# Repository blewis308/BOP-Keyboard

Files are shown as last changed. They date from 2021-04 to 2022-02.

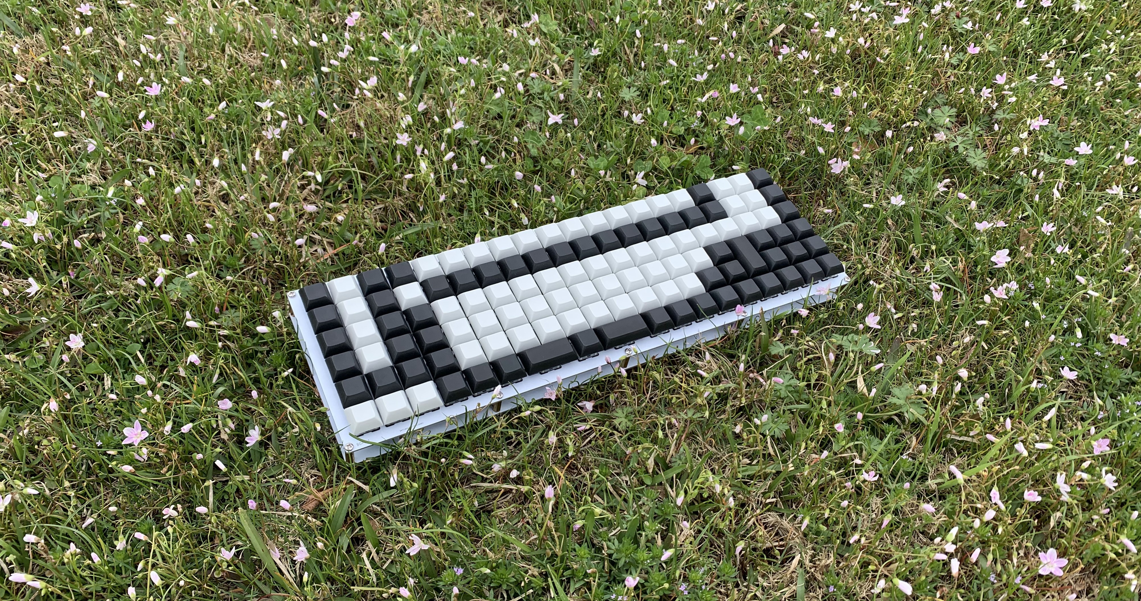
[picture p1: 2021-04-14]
Pictures/IMG_6860_cropped.jpg

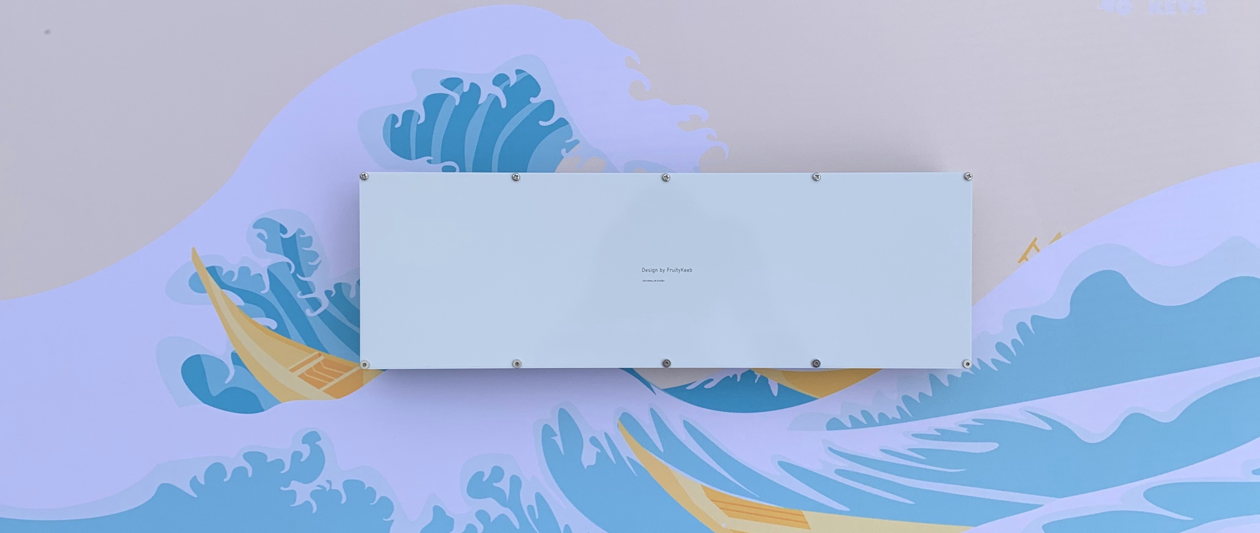
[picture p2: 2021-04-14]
Pictures/IMG_6852_cropped.jpg

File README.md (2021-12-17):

# BOP-Keyboard

BOP stands for Big Ortho Project, a 6 row by 20 column ortholinear keyboard running off of the Teensy++2.0 Controller.

## Jump to...
* [What's included](#included-in-the-box)
* [Build Guide](#build-guide)
  
## REPO Contents:
* Plate File in `.dxf` format, perfect for creating a 3D printed case from.
* Various Pictures of the Prototype boards, also shown below.
* QMK Hex and firmware coming soontm

**Open Sourced PCB Files are for PERSONAL use only. Use for Commercial purposes without written permission is strictly prohibited.**

### Pictures

Image of BOP
Image of BOP
Image of BOP

# Included in the Box:
#### Diodes - About 130x (120 needed)
Image of Diodes
#### Standoffs + Screws - M3 Size (10x Standoffs and 20x Screws)
Image of Standoffs
#### Controller Headers - 2x 20 pin male and female headers
Image of Headers
#### Stabilizers - 3x 2u Stabilizers
Image of Stabilizers
#### Rubber Feet - 8x Feet
Image of Feet
#### Controller - 1x Teensy++2.0 Micro Controller
Image of controller

# Build Guide:
## Total Estimated Time: 4-5 hours

## Before you begin! 
#### Please test your board, some boards have shown signs of multiple switches actuating at the same time or switches that are shorting out with nearby ones. You can test this by using a multimeter in continuity mode and test each pin on the socket to pins in the rows. If anything is wrong, please contact me via Discord DM or email and I'll work with you to take care of the issue.

### Step 1: Diodes
#### Estimated Time: 2-3 hours
[This is a really good video on how to solder smd diodes](https://youtu.be/Jpj3tilIaik?t=187). I recommend you watch this before soldering.

Start by orienting the PCB so that you can read "Design by Fruitykeeb" straight on. Next, place a small amound of solder the pad opposite to the "K" on each of the diode locations.

Image of half pad

Next, using tweezers or something similar, grab one diode and heat the bit of solder you just placed. Once the solder starts to melt, slide the diode into position. **Make sure the line on the diode is facing the "K" on the footprint. If it is not, key presses will not register!**

Image of diode on

Finish the diodes by adding solder to the other pad. 

### Step 2: Headers
#### Estimated Time: 5-15 minutes

Keeping on the same side as the diodes, set the female headers onto the pcb. Making sure they are straight vertically, use tape to hold them in place. 

Image of headers

Flip the pcb over and solder the headers in place. **Make sure there are no shorts between pins.**

Next, place the male headers onto the controller. The USB port should be facing up, leave the longer legs up as well. Using tape to hold them im place, flip the controller over and solder them in. Again, make sure there are no shorts between pins. 

Press the controller in to test fit, but remove for flashing and switches.

Image of controller

### Step 3: Flashing the controller
#### Estimated Time: 5 minutes

My using [QMK Toolbox](https://github.com/qmk/qmk_toolbox), Open the default hex in the /keymaps/hex folder of this repo. 

In the MCU dropdown, select the `at90usb1286` option. Plug in the Teensy++2.0 and press the reset button at the bottom, then click `Flash` in the toolbox, this will flash the controller to the keymap you specify.

Press the controller in and using Via and tweezers, bridge the contacts where the switches would be to test each key. 

> If there is an issue where the last column spams the keys, there is a workaround detailed [here](#the-workaround).

### Step 4: Switches
#### Estimated Time: 45 mins - 1 hour.

**If you are using stabilizers, put your stabilizers in now.**

Start by pressing some switches into the plate. I recommend switches placed as in the picture below, but use enough so the plate doesn't fall down.
Image of plate with switches

Flip the board over and solder in these first. **Note:** If you have a white pcb, the tolerances are tighter which makes pressing in switches harder. Double check that each switch is pressed fully in before soldering.

After these first switches are in, press in the remaining switches. Keep in mind that the top row, second column switch is rotated 180 from all the other switches.

Then, solder in the rest of the switches. Finally, press in the controller.

Image of all switches in

### Step 5: Standoffs and Bottom Plate
#### Estimated Time: 5 minutes

Start by placing a screw in the switch plate, then thread the standoff onto it. Repeat this for all 10 holes. Flip the whole board over and set the bottom plate on top; you shoudl be able to read "BOP".

Using a screw driver, screw in the remaining screws and then place the rubber feet around the edge of the board.

### Step 6: Enjoy!

Congratulations! You finished your BOP build! Add switches and start typing away!

## The Workaround:
If you have an issue with your board spamming the far right column of keys, use this workaround. 

On the bottom side of the controller, solder a short between pins C6 and C7. In the `config.h` file, change the last item in the `MATRIX_COL_PINS` array from C7 to C6.

Recompile the hex and reflash the MCU. This should fix the problem.

If this still does not work, clip the pins that go to ground from the micro controller.

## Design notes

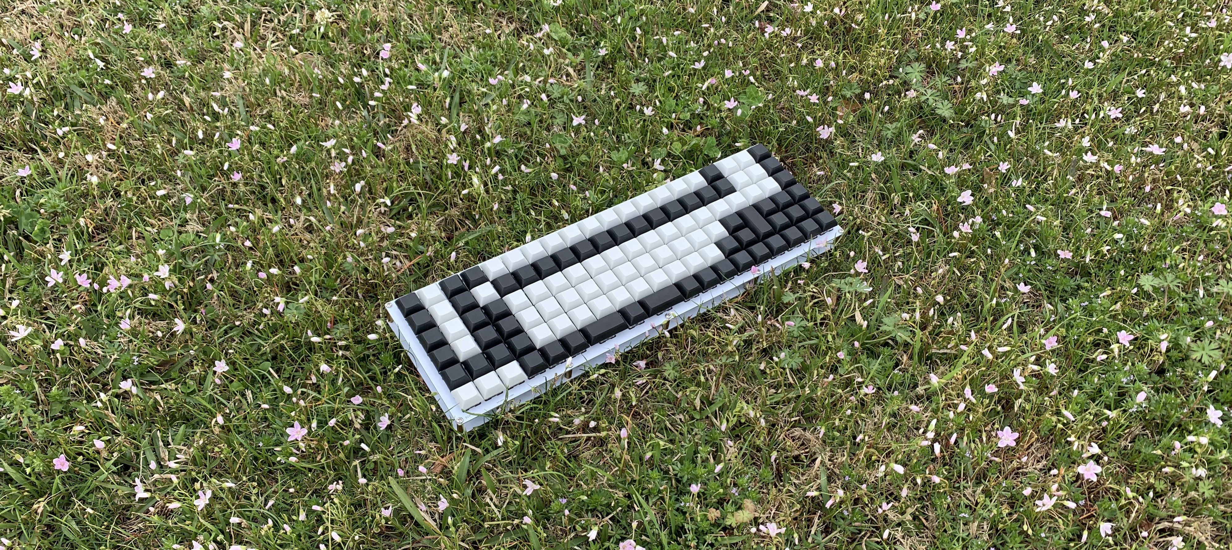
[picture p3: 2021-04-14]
Pictures/IMG_6861_cropped.jpg

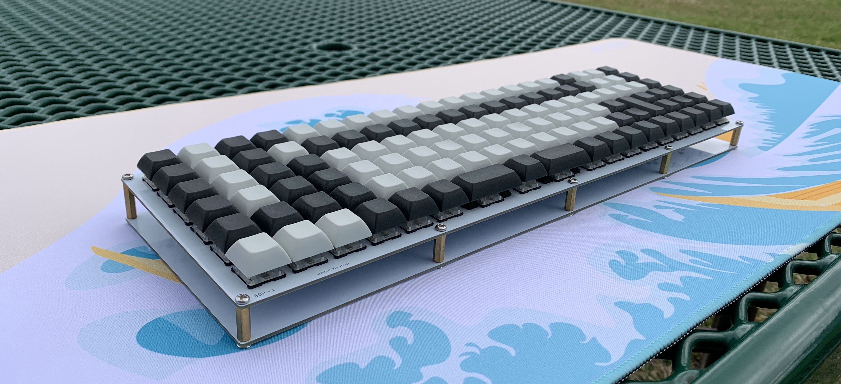
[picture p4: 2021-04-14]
Pictures/IMG_6857_cropped.jpg

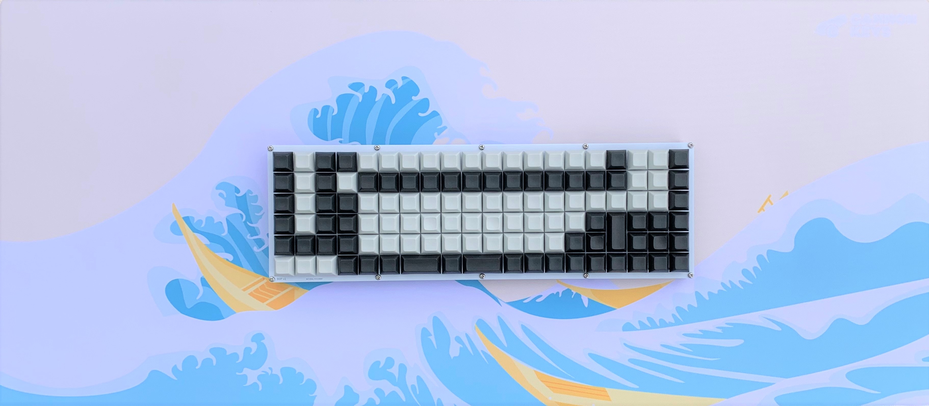
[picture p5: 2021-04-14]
Pictures/IMG_6850_cropped_filter.jpg

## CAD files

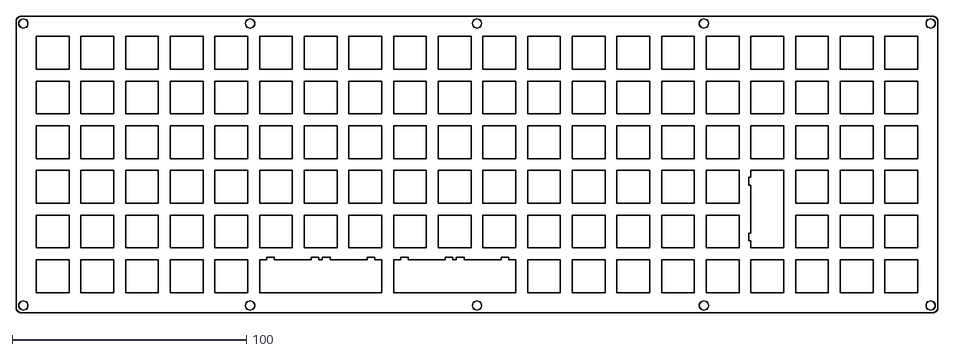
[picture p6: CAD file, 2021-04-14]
Plate/plate v1.1.dxf
393.0 x 126.3

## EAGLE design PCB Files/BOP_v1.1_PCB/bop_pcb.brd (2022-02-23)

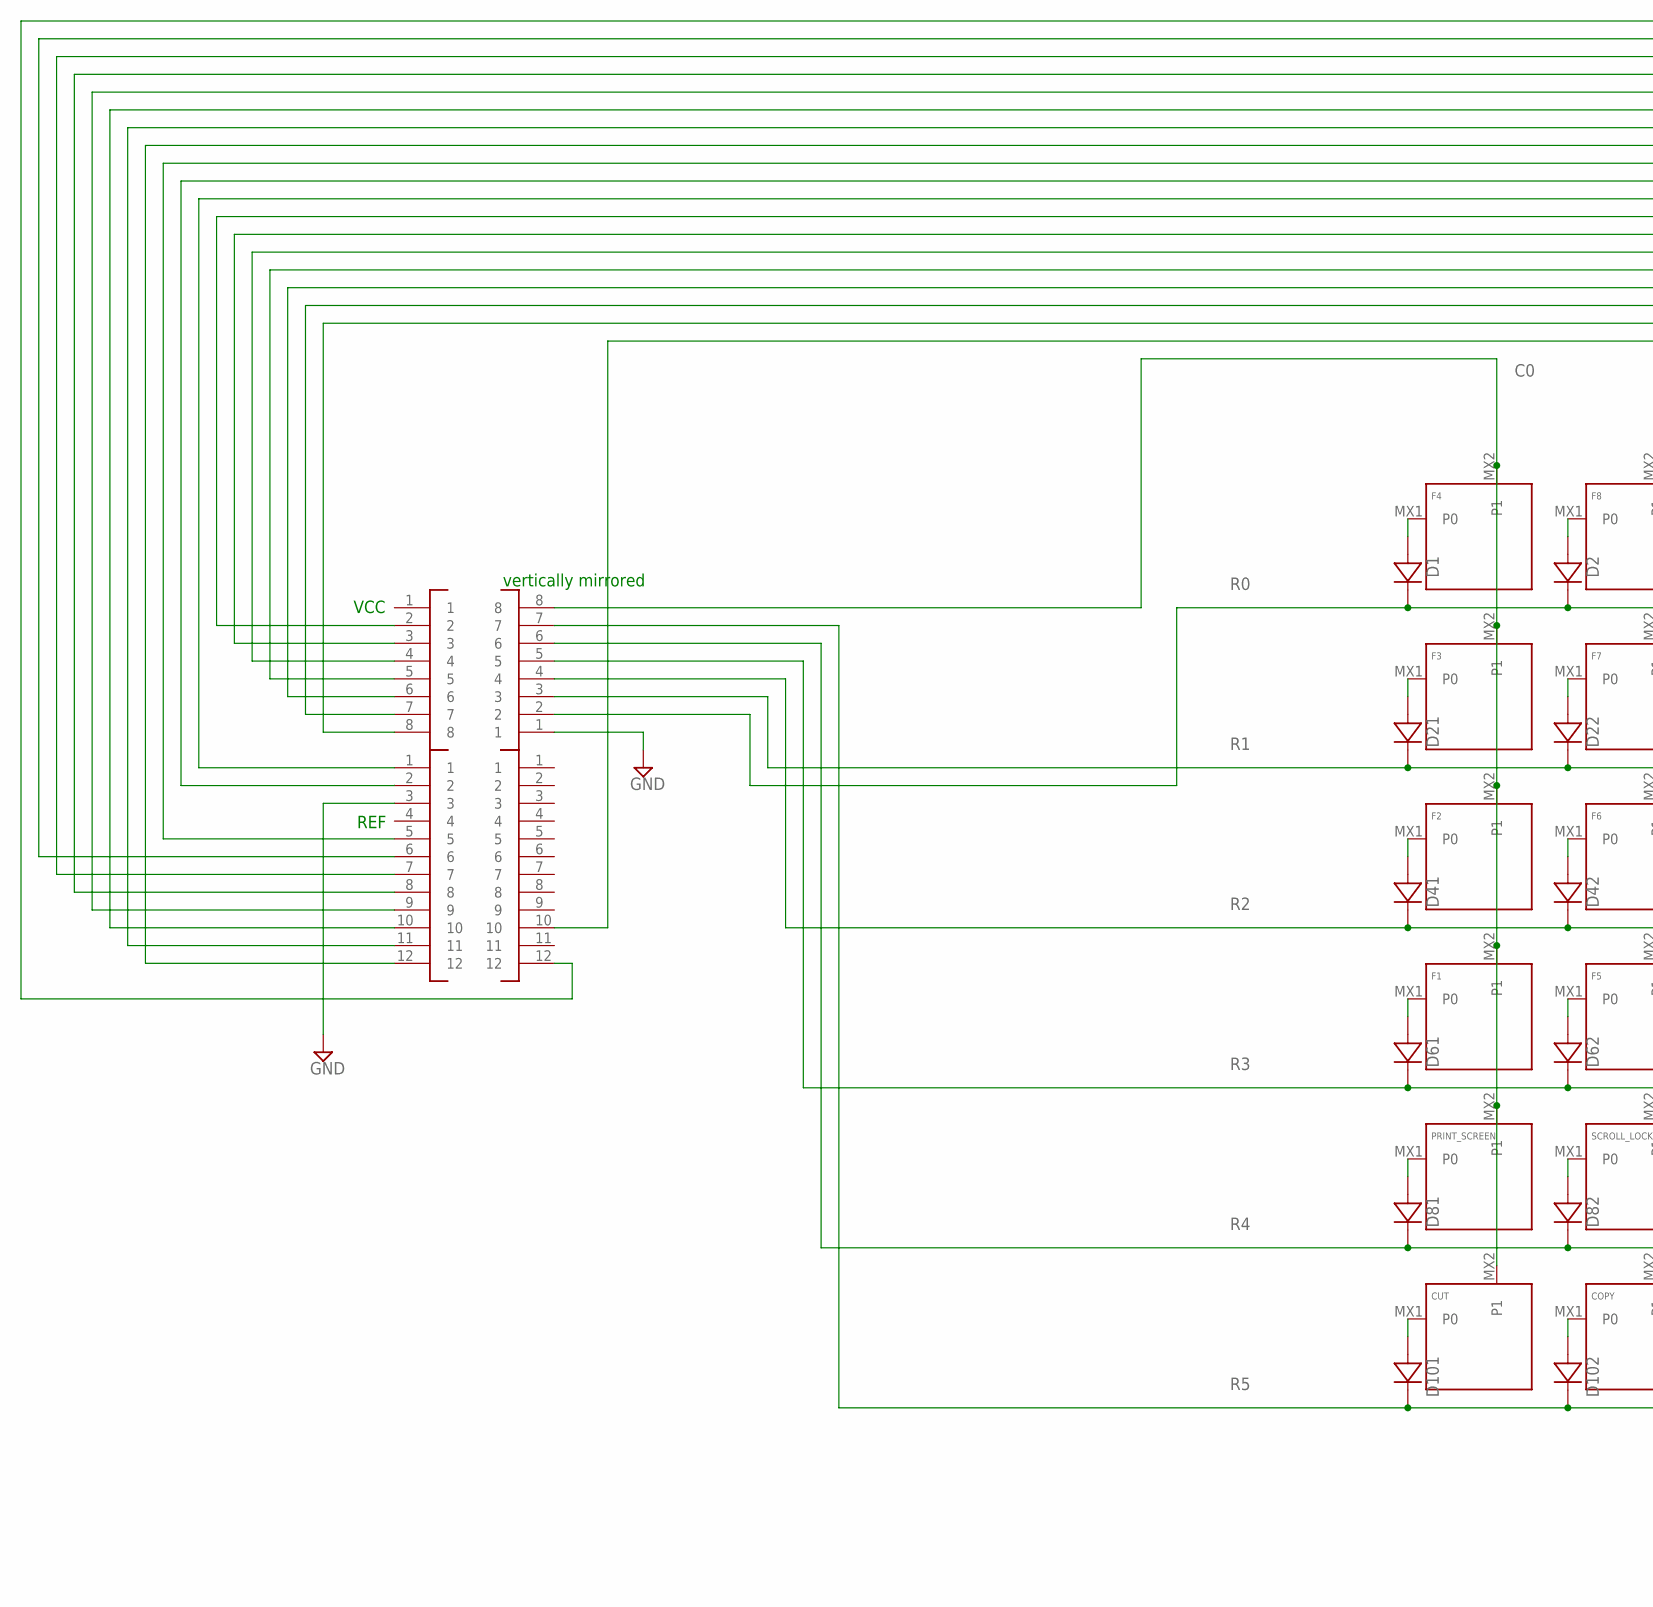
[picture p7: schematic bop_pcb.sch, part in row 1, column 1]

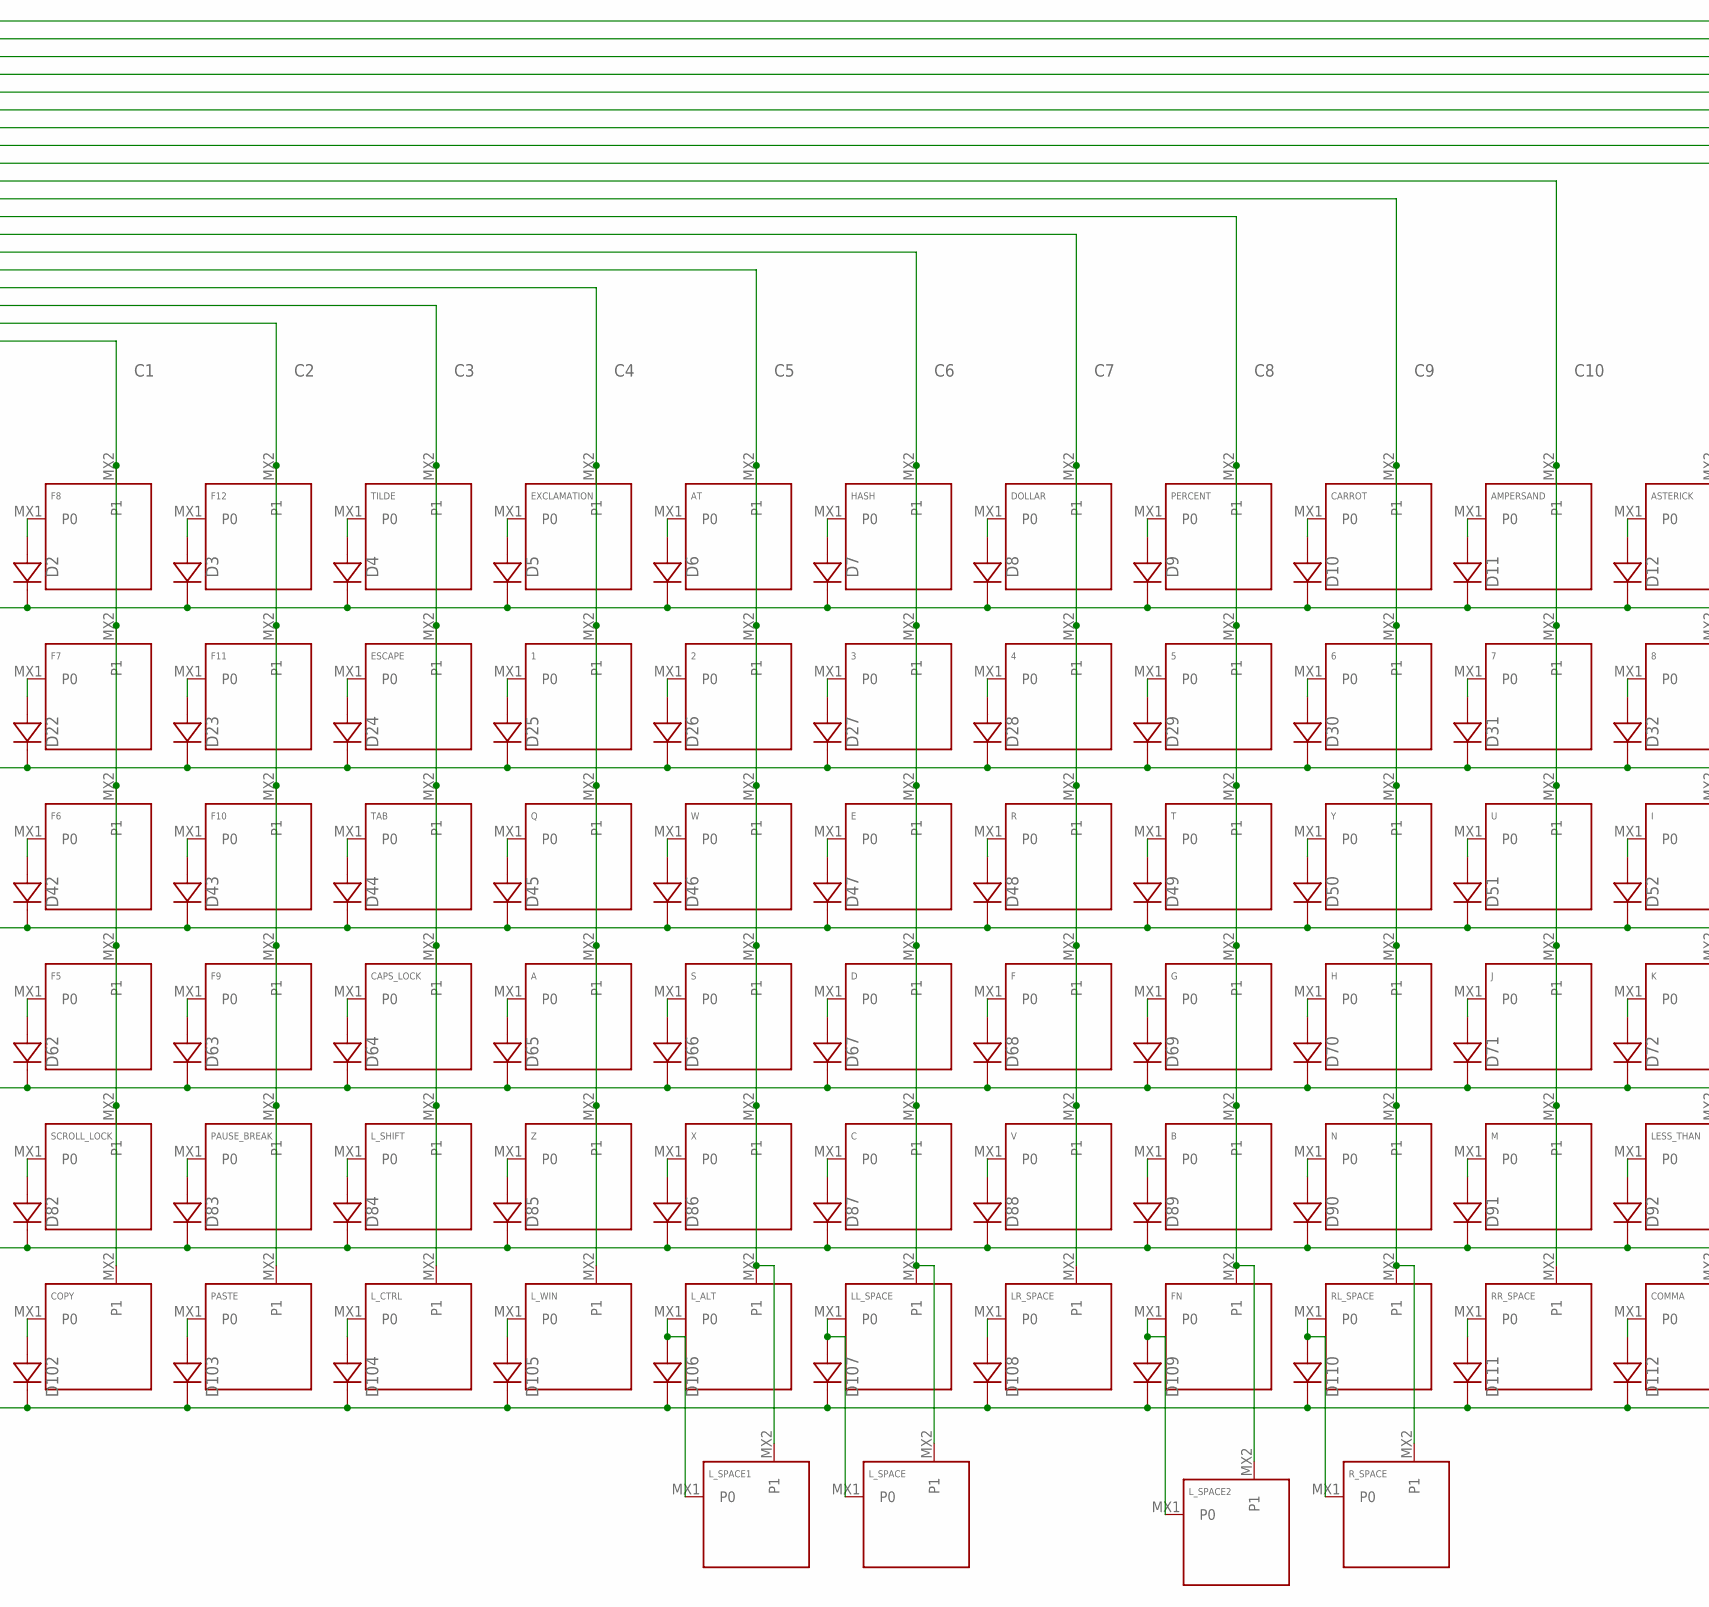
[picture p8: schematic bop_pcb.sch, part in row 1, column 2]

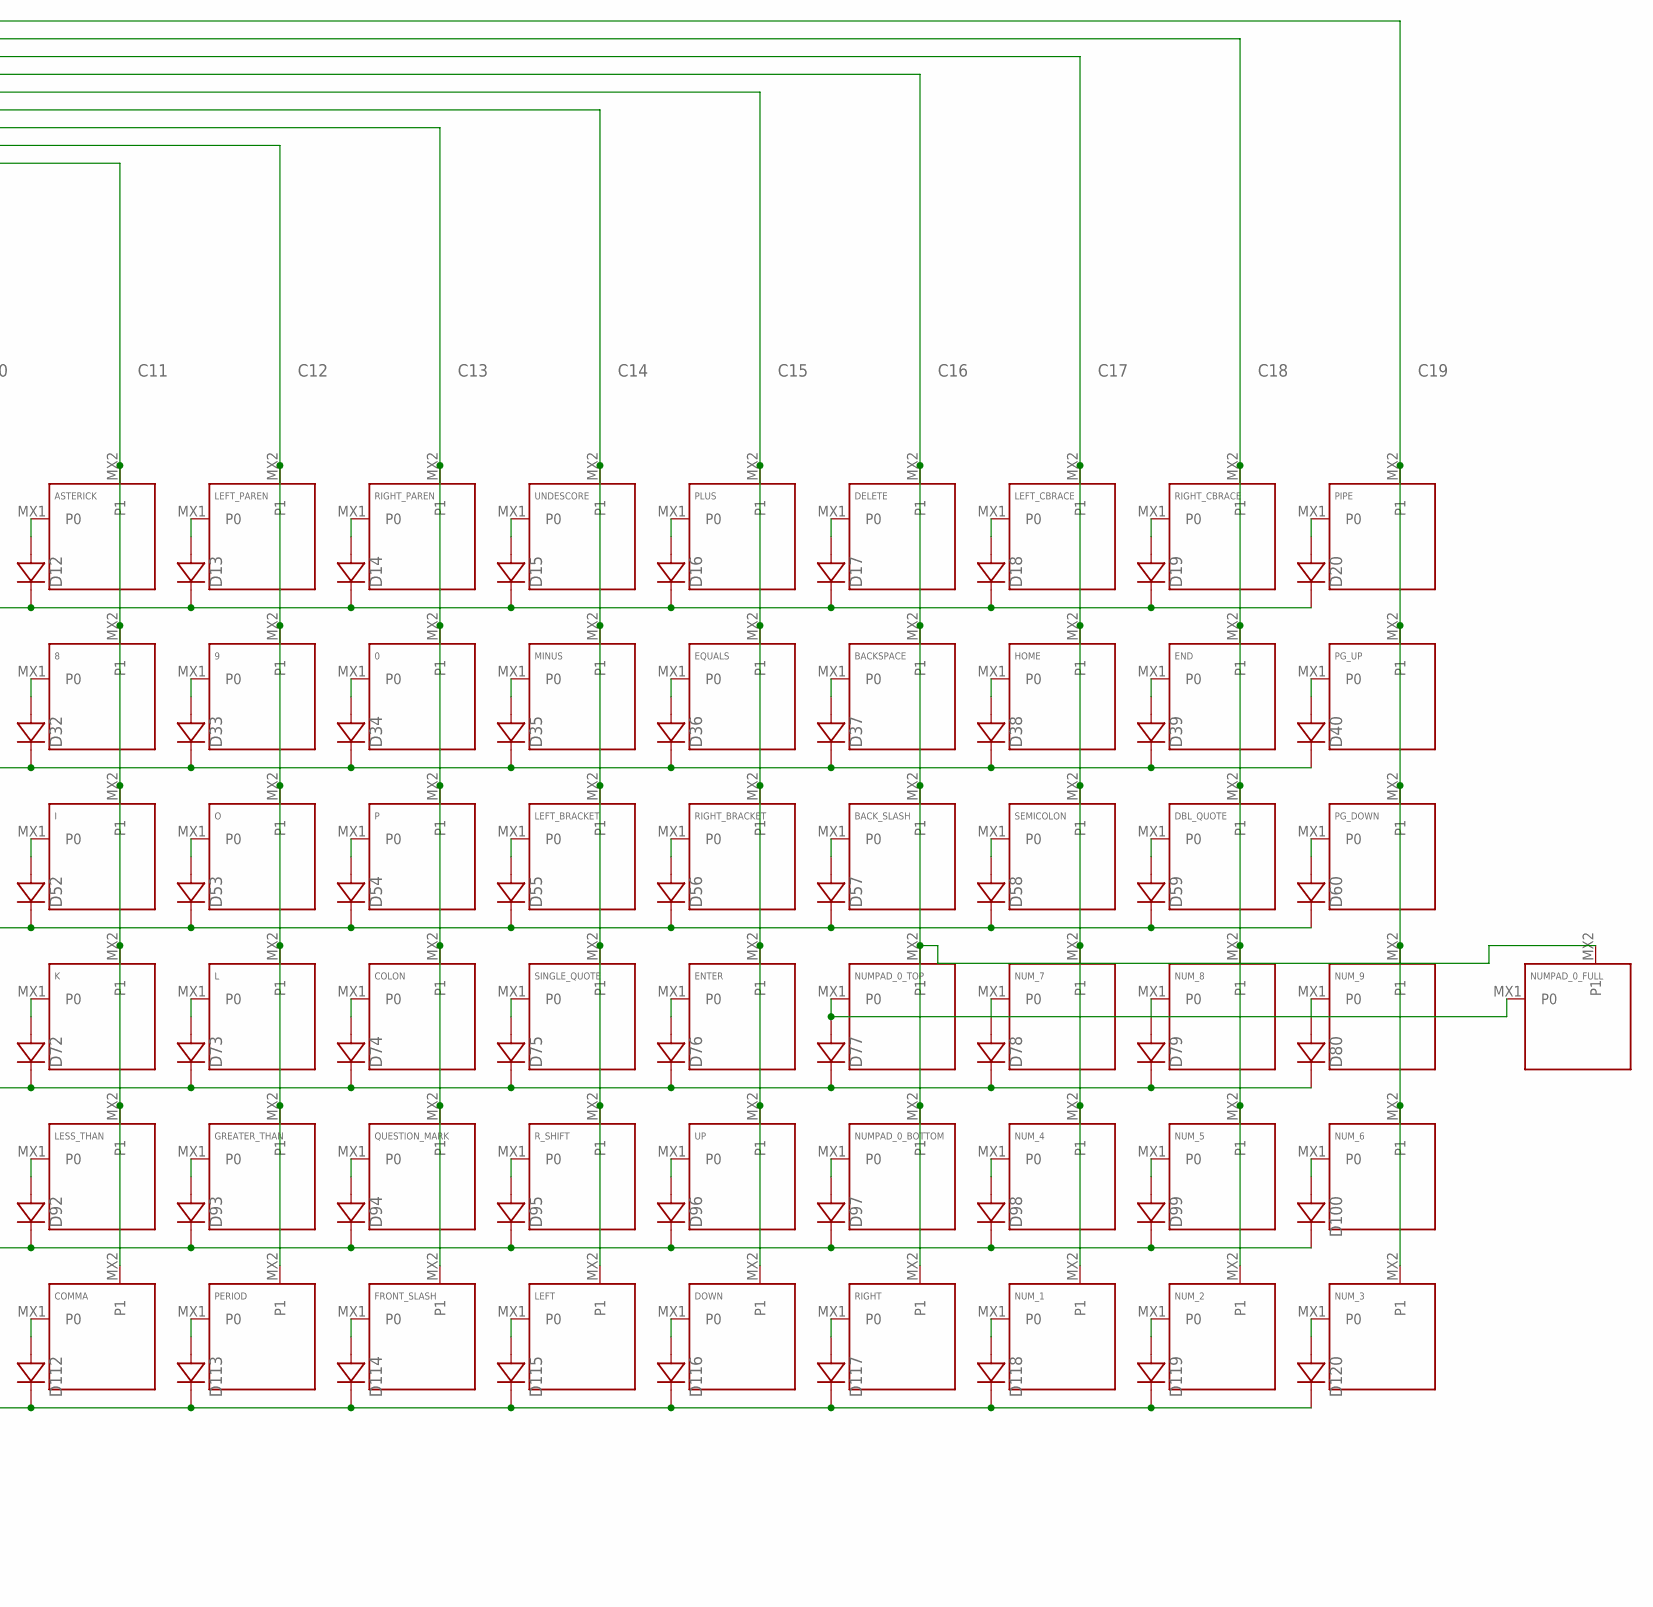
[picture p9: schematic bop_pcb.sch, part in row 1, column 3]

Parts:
0, 1, 2, 3, 4, 5, 6, 7, 8, 9: KEYSWITCH-PLAIN-MX-1U; MX-1U
A: KEYSWITCH-PLAIN-MX-1U; MX-1U
AMPERSAND: KEYSWITCH-PLAIN-MX-1U; MX-1U
ASTERICK: KEYSWITCH-PLAIN-MX-1U; MX-1U
AT: KEYSWITCH-PLAIN-MX-1U; MX-1U
B: KEYSWITCH-PLAIN-MX-1U; MX-1U
BACKSPACE: KEYSWITCH-PLAIN-MX-1U; MX-1U
BACK_SLASH: KEYSWITCH-PLAIN-MX-1U; MX-1U
C: KEYSWITCH-PLAIN-MX-1U; MX-1U
CAPS_LOCK: KEYSWITCH-PLAIN-MX-1U; MX-1U
CARROT: KEYSWITCH-PLAIN-MX-1U; MX-1U
COLON: KEYSWITCH-PLAIN-MX-1U; MX-1U
COMMA: KEYSWITCH-PLAIN-MX-1U; MX-1U
COPY: KEYSWITCH-PLAIN-MX-1U; MX-1U
CUT: KEYSWITCH-PLAIN-MX-1U; MX-1U
D: KEYSWITCH-PLAIN-MX-1U; MX-1U
D1, D2, D3, D4, D5, D6, D7, D8, D9, D10, D11, D12, D13, D14, D15, D16, D17, D18, D19, D20, D21, D22, D23, D24, D25, D26, D27, D28, D29, D30, D31, D32, D33, D34, D35, D36, D37, D38, D39, D40, D41, D42, D43, D44, D45, D46, D47, D48, D49, D50, D51, D52, D53, D54, D55, D56, D57, D58, D59, D60, D61, D62, D63, D64, D65, D66, D67, D68, D69, D70, D71, D72, D73, D74, D75, D76, D77, D78, D79, D80, D81, D82, D83, D84, D85, D86, D87, D88, D89, D90, D91, D92, D93, D94, D95, D96, D97, D98, D99, D100, D101, D102, D103, D104, D105, D106, D107, D108, D109, D110, D111, D112, D113, D114, D115, D116, D117, D118, D119, D120: DIODE-SOD-123; SOD-123
DBL_QUOTE: KEYSWITCH-PLAIN-MX-1U; MX-1U
DELETE: KEYSWITCH-PLAIN-MX-1U; MX-1U
DOLLAR: KEYSWITCH-PLAIN-MX-1U; MX-1U
DOWN: KEYSWITCH-PLAIN-MX-1U; MX-1U
E: KEYSWITCH-PLAIN-MX-1U; MX-1U
END: KEYSWITCH-PLAIN-MX-1U; MX-1U
ENTER: KEYSWITCH-PLAIN-MX-1U; MX-1U
EQUALS: KEYSWITCH-PLAIN-MX-1U; MX-1U
ESCAPE: KEYSWITCH-PLAIN-MX-1U; MX-1U
EXCLAMATION: KEYSWITCH-PLAIN-MX-1U; MX-1U
F, F1, F2, F3, F4, F5, F6, F7, F8, F9, F10, F11, F12: KEYSWITCH-PLAIN-MX-1U; MX-1U
FN: KEYSWITCH-PLAIN-MX-1U; MX-1U
FRONT_SLASH: KEYSWITCH-PLAIN-MX-1U; MX-1U
G: KEYSWITCH-PLAIN-MX-1U; MX-1U
GREATER_THAN: KEYSWITCH-PLAIN-MX-1U; MX-1U
H: KEYSWITCH-PLAIN-MX-1U; MX-1U
HASH: KEYSWITCH-PLAIN-MX-1U; MX-1U
HOME: KEYSWITCH-PLAIN-MX-1U; MX-1U
I: KEYSWITCH-PLAIN-MX-1U; MX-1U
J: KEYSWITCH-PLAIN-MX-1U; MX-1U
J1, J2: HEADER-12X1-2.54-ROUND
K: KEYSWITCH-PLAIN-MX-1U; MX-1U
L: KEYSWITCH-PLAIN-MX-1U; MX-1U
LEFT: KEYSWITCH-PLAIN-MX-1U; MX-1U
LEFT_BRACKET: KEYSWITCH-PLAIN-MX-1U; MX-1U
LEFT_CBRACE: KEYSWITCH-PLAIN-MX-1U; MX-1U
LEFT_PAREN: KEYSWITCH-PLAIN-MX-1U; MX-1U
LESS_THAN: KEYSWITCH-PLAIN-MX-1U; MX-1U
LL_SPACE: KEYSWITCH-PLAIN-MX-1U; MX-1U
LR_SPACE: KEYSWITCH-PLAIN-MX-1U; MX-1U
L_ALT: KEYSWITCH-PLAIN-MX-1U; MX-1U
L_CTRL: KEYSWITCH-PLAIN-MX-1U; MX-1U
L_SHIFT: KEYSWITCH-PLAIN-MX-1U; MX-1U
L_SPACE, L_SPACE1, L_SPACE2: KEYSWITCH-PLAIN-MX-2U; MX-2U
L_WIN: KEYSWITCH-PLAIN-MX-1U; MX-1U
M: KEYSWITCH-PLAIN-MX-1U; MX-1U
MINUS: KEYSWITCH-PLAIN-MX-1U; MX-1U
N: KEYSWITCH-PLAIN-MX-1U; MX-1U
NUMPAD_0_BOTTOM, NUMPAD_0_TOP: KEYSWITCH-PLAIN-MX-1U; MX-1U
NUMPAD_0_FULL: KEYSWITCH-PLAIN-MX-2U; MX-2U
NUM_1, NUM_2, NUM_3, NUM_4, NUM_5, NUM_6, NUM_7, NUM_8, NUM_9: KEYSWITCH-PLAIN-MX-1U; MX-1U
O: KEYSWITCH-PLAIN-MX-1U; MX-1U
P: KEYSWITCH-PLAIN-MX-1U; MX-1U
PASTE: KEYSWITCH-PLAIN-MX-1U; MX-1U
PAUSE_BREAK: KEYSWITCH-PLAIN-MX-1U; MX-1U
PERCENT: KEYSWITCH-PLAIN-MX-1U; MX-1U
PERIOD: KEYSWITCH-PLAIN-MX-1U; MX-1U
PG_DOWN: KEYSWITCH-PLAIN-MX-1U; MX-1U
PG_UP: KEYSWITCH-PLAIN-MX-1U; MX-1U
PIPE: KEYSWITCH-PLAIN-MX-1U; MX-1U
PLUS: KEYSWITCH-PLAIN-MX-1U; MX-1U
PRINT_SCREEN: KEYSWITCH-PLAIN-MX-1U; MX-1U
Q: KEYSWITCH-PLAIN-MX-1U; MX-1U
QUESTION_MARK: KEYSWITCH-PLAIN-MX-1U; MX-1U
R: KEYSWITCH-PLAIN-MX-1U; MX-1U
RIGHT: KEYSWITCH-PLAIN-MX-1U; MX-1U
RIGHT_BRACKET: KEYSWITCH-PLAIN-MX-1U; MX-1U
RIGHT_CBRACE: KEYSWITCH-PLAIN-MX-1U; MX-1U
RIGHT_PAREN: KEYSWITCH-PLAIN-MX-1U; MX-1U
RL_SPACE: KEYSWITCH-PLAIN-MX-1U; MX-1U
RR_SPACE: KEYSWITCH-PLAIN-MX-1U; MX-1U
R_SHIFT: KEYSWITCH-PLAIN-MX-1U; MX-1U
R_SPACE: KEYSWITCH-PLAIN-MX-2U; MX-2U
S: KEYSWITCH-PLAIN-MX-1U; MX-1U
SCROLL_LOCK: KEYSWITCH-PLAIN-MX-1U; MX-1U
SEMICOLON: KEYSWITCH-PLAIN-MX-1U; MX-1U
SINGLE_QUOTE: KEYSWITCH-PLAIN-MX-1U; MX-1U
T: KEYSWITCH-PLAIN-MX-1U; MX-1U
TAB: KEYSWITCH-PLAIN-MX-1U; MX-1U
TILDE: KEYSWITCH-PLAIN-MX-1U; MX-1U
U: KEYSWITCH-PLAIN-MX-1U; MX-1U
U$1, U$2: HEADER-8X1-2.54
UNDESCORE: KEYSWITCH-PLAIN-MX-1U; MX-1U
UP: KEYSWITCH-PLAIN-MX-1U; MX-1U
V: KEYSWITCH-PLAIN-MX-1U; MX-1U
W: KEYSWITCH-PLAIN-MX-1U; MX-1U
X: KEYSWITCH-PLAIN-MX-1U; MX-1U
Y: KEYSWITCH-PLAIN-MX-1U; MX-1U
Z: KEYSWITCH-PLAIN-MX-1U; MX-1U

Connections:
C0: CUT.MX2 (P1), F1.MX2 (P1), F2.MX2 (P1), F3.MX2 (P1), F4.MX2 (P1), PRINT_SCREEN.MX2 (P1), U$2.8
C1: COPY.MX2 (P1), F5.MX2 (P1), F6.MX2 (P1), F7.MX2 (P1), F8.MX2 (P1), J1.10, SCROLL_LOCK.MX2 (P1)
C2: F9.MX2 (P1), F10.MX2 (P1), F11.MX2 (P1), F12.MX2 (P1), PASTE.MX2 (P1), PAUSE_BREAK.MX2 (P1), U$1.8
C3: CAPS_LOCK.MX2 (P1), ESCAPE.MX2 (P1), L_CTRL.MX2 (P1), L_SHIFT.MX2 (P1), TAB.MX2 (P1), TILDE.MX2 (P1), U$1.7
C4: 1.MX2 (P1), A.MX2 (P1), EXCLAMATION.MX2 (P1), L_WIN.MX2 (P1), Q.MX2 (P1), U$1.6, Z.MX2 (P1)
C5: 2.MX2 (P1), AT.MX2 (P1), L_ALT.MX2 (P1), L_SPACE1.MX2 (P1), S.MX2 (P1), U$1.5, W.MX2 (P1), X.MX2 (P1)
C6: 3.MX2 (P1), C.MX2 (P1), D.MX2 (P1), E.MX2 (P1), HASH.MX2 (P1), LL_SPACE.MX2 (P1), L_SPACE.MX2 (P1), U$1.4
C7: 4.MX2 (P1), DOLLAR.MX2 (P1), F.MX2 (P1), LR_SPACE.MX2 (P1), R.MX2 (P1), U$1.3, V.MX2 (P1)
C8: 5.MX2 (P1), B.MX2 (P1), FN.MX2 (P1), G.MX2 (P1), L_SPACE2.MX2 (P1), PERCENT.MX2 (P1), T.MX2 (P1), U$1.2
C9: 6.MX2 (P1), CARROT.MX2 (P1), H.MX2 (P1), J2.1, N.MX2 (P1), RL_SPACE.MX2 (P1), R_SPACE.MX2 (P1), Y.MX2 (P1)
C10: 7.MX2 (P1), AMPERSAND.MX2 (P1), J.MX2 (P1), J2.2, M.MX2 (P1), RR_SPACE.MX2 (P1), U.MX2 (P1)
C11: 8.MX2 (P1), ASTERICK.MX2 (P1), COMMA.MX2 (P1), I.MX2 (P1), J2.5, K.MX2 (P1), LESS_THAN.MX2 (P1)
C12: 9.MX2 (P1), GREATER_THAN.MX2 (P1), J2.12, L.MX2 (P1), LEFT_PAREN.MX2 (P1), O.MX2 (P1), PERIOD.MX2 (P1)
C13: 0.MX2 (P1), COLON.MX2 (P1), FRONT_SLASH.MX2 (P1), J2.11, P.MX2 (P1), QUESTION_MARK.MX2 (P1), RIGHT_PAREN.MX2 (P1)
C14: J2.10, LEFT.MX2 (P1), LEFT_BRACKET.MX2 (P1), MINUS.MX2 (P1), R_SHIFT.MX2 (P1), SINGLE_QUOTE.MX2 (P1), UNDESCORE.MX2 (P1)
C15: DOWN.MX2 (P1), ENTER.MX2 (P1), EQUALS.MX2 (P1), J2.9, PLUS.MX2 (P1), RIGHT_BRACKET.MX2 (P1), UP.MX2 (P1)
C16: BACKSPACE.MX2 (P1), BACK_SLASH.MX2 (P1), DELETE.MX2 (P1), J2.8, NUMPAD_0_BOTTOM.MX2 (P1), NUMPAD_0_FULL.MX2 (P1), NUMPAD_0_TOP.MX2 (P1), RIGHT.MX2 (P1)
C17: HOME.MX2 (P1), J2.7, LEFT_CBRACE.MX2 (P1), NUM_1.MX2 (P1), NUM_4.MX2 (P1), NUM_7.MX2 (P1), SEMICOLON.MX2 (P1)
C18: DBL_QUOTE.MX2 (P1), END.MX2 (P1), J2.6, NUM_2.MX2 (P1), NUM_5.MX2 (P1), NUM_8.MX2 (P1), RIGHT_CBRACE.MX2 (P1)
C19: J1.12, NUM_3.MX2 (P1), NUM_6.MX2 (P1), NUM_9.MX2 (P1), PG_DOWN.MX2 (P1), PG_UP.MX2 (P1), PIPE.MX2 (P1)
GND: J2.3, U$2.1
unnamed: D1.A, F4.MX1 (P0)
unnamed: D2.A, F8.MX1 (P0)
unnamed: D3.A, F12.MX1 (P0)
unnamed: D4.A, TILDE.MX1 (P0)
unnamed: D5.A, EXCLAMATION.MX1 (P0)
unnamed: AT.MX1 (P0), D6.A
unnamed: D7.A, HASH.MX1 (P0)
unnamed: D8.A, DOLLAR.MX1 (P0)
unnamed: D9.A, PERCENT.MX1 (P0)
unnamed: CARROT.MX1 (P0), D10.A
unnamed: AMPERSAND.MX1 (P0), D11.A
unnamed: ASTERICK.MX1 (P0), D12.A
unnamed: D13.A, LEFT_PAREN.MX1 (P0)
unnamed: D14.A, RIGHT_PAREN.MX1 (P0)
unnamed: D15.A, UNDESCORE.MX1 (P0)
unnamed: D16.A, PLUS.MX1 (P0)
unnamed: D17.A, DELETE.MX1 (P0)
unnamed: D18.A, LEFT_CBRACE.MX1 (P0)
unnamed: D19.A, RIGHT_CBRACE.MX1 (P0)
unnamed: D20.A, PIPE.MX1 (P0)
unnamed: D21.A, F3.MX1 (P0)
unnamed: D22.A, F7.MX1 (P0)
unnamed: D23.A, F11.MX1 (P0)
unnamed: D24.A, ESCAPE.MX1 (P0)
unnamed: 1.MX1 (P0), D25.A
unnamed: 2.MX1 (P0), D26.A
unnamed: 3.MX1 (P0), D27.A
unnamed: 4.MX1 (P0), D28.A
unnamed: 5.MX1 (P0), D29.A
unnamed: 6.MX1 (P0), D30.A
unnamed: 7.MX1 (P0), D31.A
unnamed: 8.MX1 (P0), D32.A
unnamed: 9.MX1 (P0), D33.A
unnamed: 0.MX1 (P0), D34.A
unnamed: D35.A, MINUS.MX1 (P0)
unnamed: D36.A, EQUALS.MX1 (P0)
unnamed: BACKSPACE.MX1 (P0), D37.A
unnamed: D38.A, HOME.MX1 (P0)
unnamed: D39.A, END.MX1 (P0)
unnamed: D40.A, PG_UP.MX1 (P0)
unnamed: D41.A, F2.MX1 (P0)
unnamed: D42.A, F6.MX1 (P0)
unnamed: D43.A, F10.MX1 (P0)
unnamed: D44.A, TAB.MX1 (P0)
unnamed: D45.A, Q.MX1 (P0)
unnamed: D46.A, W.MX1 (P0)
unnamed: D47.A, E.MX1 (P0)
unnamed: D48.A, R.MX1 (P0)
unnamed: D49.A, T.MX1 (P0)
unnamed: D50.A, Y.MX1 (P0)
unnamed: D51.A, U.MX1 (P0)
unnamed: D52.A, I.MX1 (P0)
unnamed: D53.A, O.MX1 (P0)
unnamed: D54.A, P.MX1 (P0)
unnamed: D55.A, LEFT_BRACKET.MX1 (P0)
unnamed: D56.A, RIGHT_BRACKET.MX1 (P0)
unnamed: BACK_SLASH.MX1 (P0), D57.A
unnamed: D58.A, SEMICOLON.MX1 (P0)
unnamed: D59.A, DBL_QUOTE.MX1 (P0)
unnamed: D60.A, PG_DOWN.MX1 (P0)
unnamed: D61.A, F1.MX1 (P0)
unnamed: D62.A, F5.MX1 (P0)
unnamed: D63.A, F9.MX1 (P0)
unnamed: CAPS_LOCK.MX1 (P0), D64.A
unnamed: A.MX1 (P0), D65.A
unnamed: D66.A, S.MX1 (P0)
unnamed: D.MX1 (P0), D67.A
unnamed: D68.A, F.MX1 (P0)
unnamed: D69.A, G.MX1 (P0)
unnamed: D70.A, H.MX1 (P0)
unnamed: D71.A, J.MX1 (P0)
unnamed: D72.A, K.MX1 (P0)
unnamed: D73.A, L.MX1 (P0)
unnamed: COLON.MX1 (P0), D74.A
unnamed: D75.A, SINGLE_QUOTE.MX1 (P0)
unnamed: D76.A, ENTER.MX1 (P0)
unnamed: D77.A, NUMPAD_0_FULL.MX1 (P0), NUMPAD_0_TOP.MX1 (P0)
unnamed: D79.A, NUM_8.MX1 (P0)
unnamed: D80.A, NUM_9.MX1 (P0)
unnamed: D81.A, PRINT_SCREEN.MX1 (P0)
unnamed: D82.A, SCROLL_LOCK.MX1 (P0)
unnamed: D83.A, PAUSE_BREAK.MX1 (P0)
unnamed: D84.A, L_SHIFT.MX1 (P0)
unnamed: D85.A, Z.MX1 (P0)
unnamed: D86.A, X.MX1 (P0)
unnamed: C.MX1 (P0), D87.A
unnamed: D88.A, V.MX1 (P0)
unnamed: B.MX1 (P0), D89.A
unnamed: D90.A, N.MX1 (P0)
unnamed: D91.A, M.MX1 (P0)
unnamed: D92.A, LESS_THAN.MX1 (P0)
unnamed: D93.A, GREATER_THAN.MX1 (P0)
unnamed: D94.A, QUESTION_MARK.MX1 (P0)
unnamed: D95.A, R_SHIFT.MX1 (P0)
unnamed: D96.A, UP.MX1 (P0)
unnamed: D97.A, NUMPAD_0_BOTTOM.MX1 (P0)
unnamed: D98.A, NUM_4.MX1 (P0)
unnamed: D99.A, NUM_5.MX1 (P0)
unnamed: D100.A, NUM_6.MX1 (P0)
unnamed: CUT.MX1 (P0), D101.A
unnamed: COPY.MX1 (P0), D102.A
unnamed: D103.A, PASTE.MX1 (P0)
unnamed: D104.A, L_CTRL.MX1 (P0)
unnamed: D105.A, L_WIN.MX1 (P0)
unnamed: D106.A, L_ALT.MX1 (P0), L_SPACE1.MX1 (P0)
unnamed: D107.A, LL_SPACE.MX1 (P0), L_SPACE.MX1 (P0)
unnamed: D108.A, LR_SPACE.MX1 (P0)
unnamed: D109.A, FN.MX1 (P0), L_SPACE2.MX1 (P0)
unnamed: D110.A, RL_SPACE.MX1 (P0), R_SPACE.MX1 (P0)
unnamed: D111.A, RR_SPACE.MX1 (P0)
unnamed: COMMA.MX1 (P0), D112.A
unnamed: D113.A, PERIOD.MX1 (P0)
unnamed: D114.A, FRONT_SLASH.MX1 (P0)
unnamed: D115.A, LEFT.MX1 (P0)
unnamed: D116.A, DOWN.MX1 (P0)
unnamed: D117.A, RIGHT.MX1 (P0)
unnamed: D118.A, NUM_1.MX1 (P0)
unnamed: D119.A, NUM_2.MX1 (P0)
unnamed: D120.A, NUM_3.MX1 (P0)
unnamed: D78.A, NUM_7.MX1 (P0)
R0: D1.C, D2.C, D3.C, D4.C, D5.C, D6.C, D7.C, D8.C, D9.C, D10.C, D11.C, D12.C, D13.C, D14.C, D15.C, D16.C, D17.C, D18.C, D19.C, D20.C, U$2.2
R1: D21.C, D22.C, D23.C, D24.C, D25.C, D26.C, D27.C, D28.C, D29.C, D30.C, D31.C, D32.C, D33.C, D34.C, D35.C, D36.C, D37.C, D38.C, D39.C, D40.C, U$2.3
R2: D41.C, D42.C, D43.C, D44.C, D45.C, D46.C, D47.C, D48.C, D49.C, D50.C, D51.C, D52.C, D53.C, D54.C, D55.C, D56.C, D57.C, D58.C, D59.C, D60.C, U$2.4
R3: D61.C, D62.C, D63.C, D64.C, D65.C, D66.C, D67.C, D68.C, D69.C, D70.C, D71.C, D72.C, D73.C, D74.C, D75.C, D76.C, D77.C, D78.C, D79.C, D80.C, U$2.5
R4: D81.C, D82.C, D83.C, D84.C, D85.C, D86.C, D87.C, D88.C, D89.C, D90.C, D91.C, D92.C, D93.C, D94.C, D95.C, D96.C, D97.C, D98.C, D99.C, D100.C, U$2.6
R5: D101.C, D102.C, D103.C, D104.C, D105.C, D106.C, D107.C, D108.C, D109.C, D110.C, D111.C, D112.C, D113.C, D114.C, D115.C, D116.C, D117.C, D118.C, D119.C, D120.C, U$2.7

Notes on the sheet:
VCC
REF
vertically mirrored

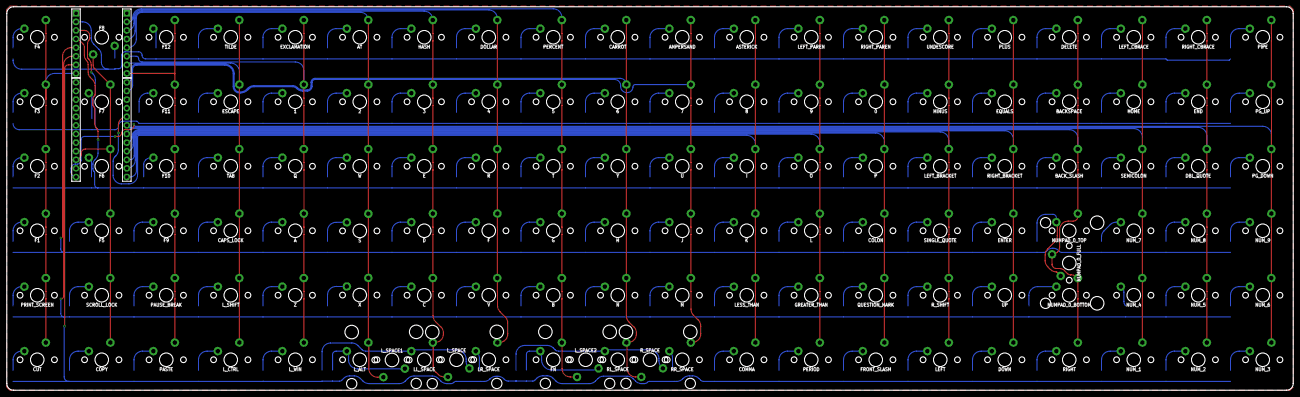
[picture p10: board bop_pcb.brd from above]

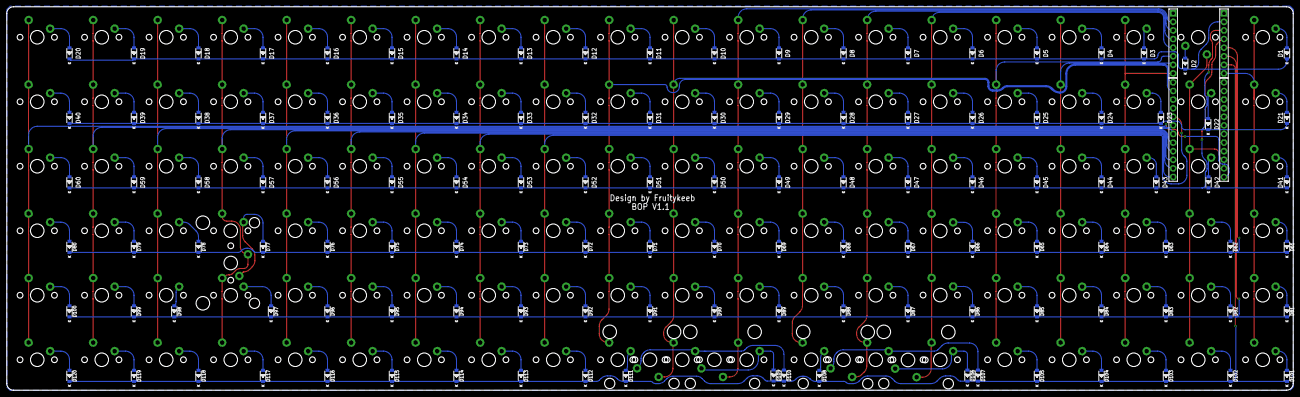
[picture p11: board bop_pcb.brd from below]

Board: 2 copper layers, 379.9 x 113.2 mm, 249 parts (120 on the bottom side), 147 nets.

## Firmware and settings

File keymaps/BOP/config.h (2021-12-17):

#pragma once

#include "config_common.h"

/* USB Device descriptor parameter */
#define VENDOR_ID       0x666B
#define PRODUCT_ID      0x626F
#define DEVICE_VER      0x0001
#define MANUFACTURER    fruitykeeb
#define PRODUCT         bop
#define DESCRIPTION     bop is a 6x20 ortholinear keyboard that uses the Teensy++2.0 Controller

/* key matrix size */
#define MATRIX_ROWS 6
#define MATRIX_COLS 20

/* key matrix pins */
#define MATRIX_ROW_PINS { B7, D0, D1, D2, D3, D4 }
#define MATRIX_COL_PINS { D5, C5, B0, B1, B2, B3, B4, B5, B6, E7, E6, F0, F7, F6, F5, F4, F3, F2, F1, C7 }
//    If your board is spamming the end column, change C7 to C6 in the line above and short those pins on the controller
                        
#define UNUSED_PINS

/* COL2ROW or ROW2COL */
#define DIODE_DIRECTION COL2ROW

/* Set 0 if debouncing isn't needed */
#define DEBOUNCING_DELAY 5

/* Mechanical locking support. Use KC_LCAP, KC_LNUM or KC_LSCR instead in keymap */
#define LOCKING_SUPPORT_ENABLE

/* Locking resynchronize hack */
#define LOCKING_RESYNC_ENABLE

/* prevent stuck modifiers */
#define PREVENT_STUCK_MODIFIERS

/* Unicode select mode */
#define UNICODE_SELECTED_MODES UC_MAC, UC_LNX, UC_WINC

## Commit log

2021-04-14 Updated plate and pictures
    [plate v1.1.dxf]
2021-05-18 added c6 fix hex
    [config.h]
2021-06-02 Multi layout support
    Added layout options for 2u long keys on appropriate places on board
2021-12-17 open sourced
    [bop_pcb.brd, bop_pcb.sch, bottom.brd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]
2022-02-23 added v1.1 pcb
    [bop_pcb.brd, bop_pcb.sch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]
